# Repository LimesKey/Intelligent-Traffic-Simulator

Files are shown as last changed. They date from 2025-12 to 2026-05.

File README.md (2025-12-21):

# Intelligent-Traffic-Simulator

> [!NOTE]
> Work in progress - Everything has shown to be working individually but has not came together as a whole yet

Detect how hot wheels cars navigate streets and interact with stop lights and how this can be applied to the real world. Just a thing I made for class

It detects hot wheels cars via the three coils embedded in the PCB traces. The coils are hooked up to a 555 timer at around 200 KHz and when the hot wheels car is over the coil, the frequency changes which is detected by the ESP32 running a pulse counter script. Essentially a metal/object detector specifically calibrated for hot wheels cars.

Potentiometers are just for debugging / testing out various configurations. There is a multiplexer hooked up to the ESP32 so that one microcontroller can control multiple LEDs for multiple traffic lights.

I made some small mistakes, but I believe I updated the schematic to reflect the changes I made to make it work.

### Todo: 
* better ESD/current backflow protection 
* have esp32 fully inside PCB outline rather than sticking out
* remove extra testpoints / optvbvvcional components now that I know what works
* look into using a general oscillator rather than a 555 timer for better performance/cost
* somehow make the usb-c connector much easier to solder, it's killing me how difficult it is
* integrate `object-detection.ino` with `dutch_traffic_light_code.ino`

# Media
## JLCPCB Ordered, Hand Assembled
<p align="center">
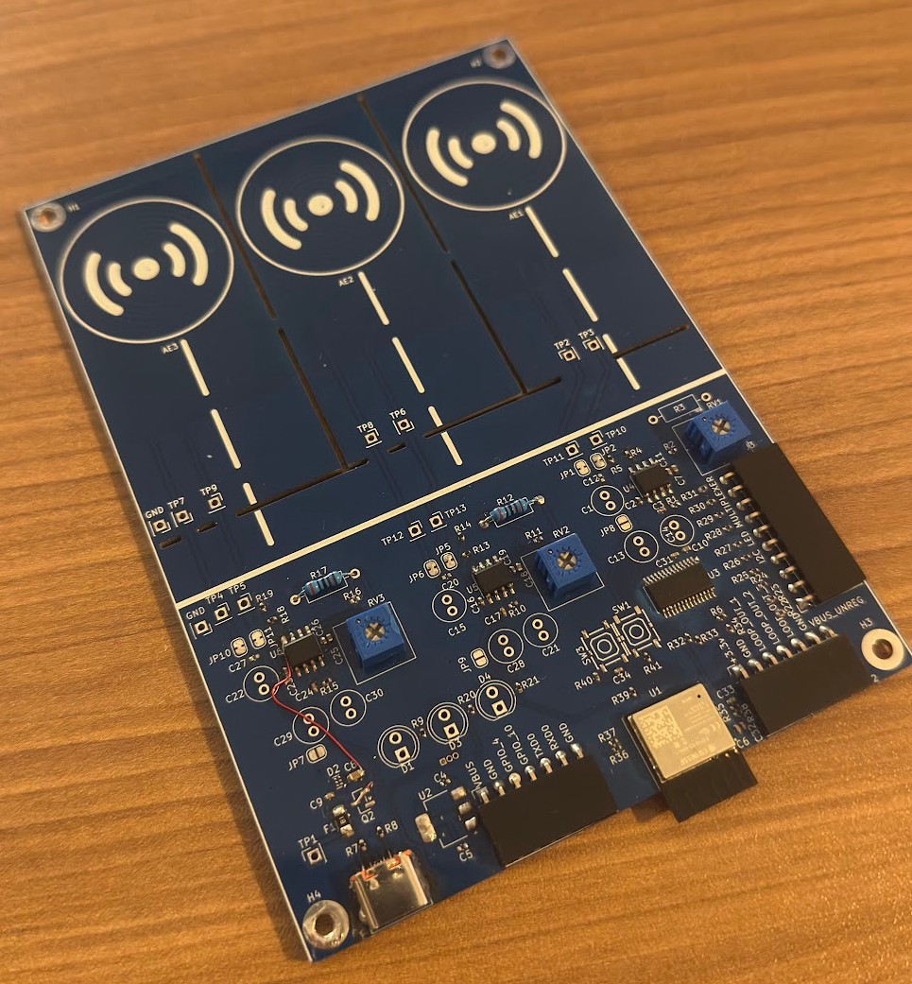
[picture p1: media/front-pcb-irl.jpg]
Assembled PCB front
  
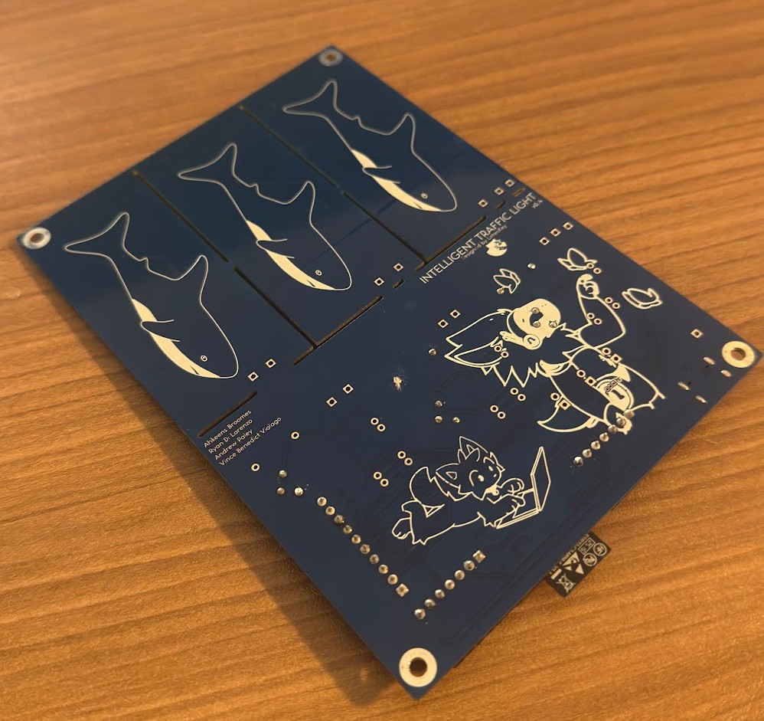
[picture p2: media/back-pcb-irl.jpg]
Assembled PCB back
  
</p>

## KiCad
### PCB 3D Viewer
<div style="display:flex; justify-content:center; gap:16px;">
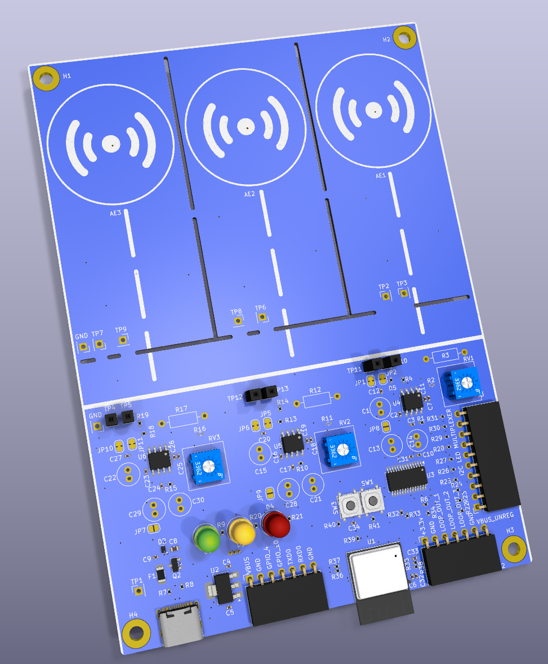
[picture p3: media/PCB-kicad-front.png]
KiCad PCB front
  
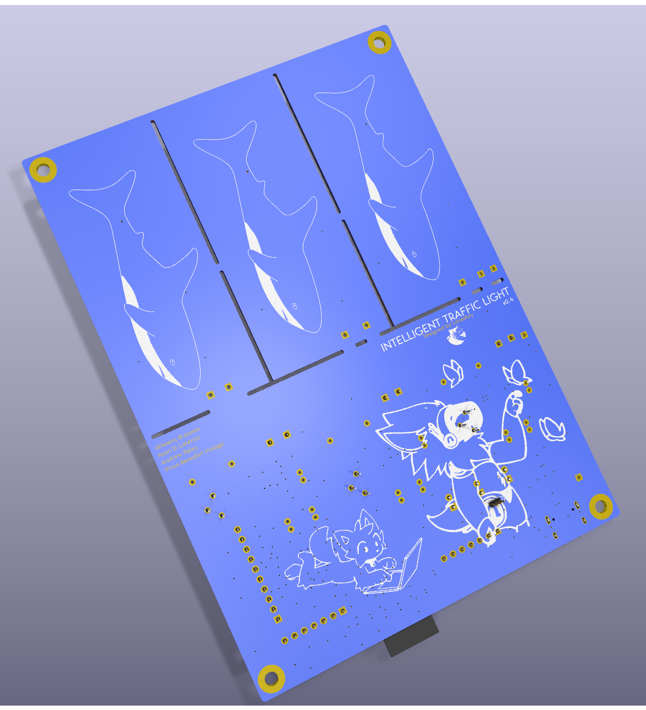
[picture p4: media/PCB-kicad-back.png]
KiCad PCB back
  
</div>

### Schematic

<h4 align="center">Main controller</h4>
KiCad Schematic of main control electronics like microcontroler / signal processing

<h4 align="center">555 Timer Circuitry</h4>
KiCad Schematic of metal detecting circuit

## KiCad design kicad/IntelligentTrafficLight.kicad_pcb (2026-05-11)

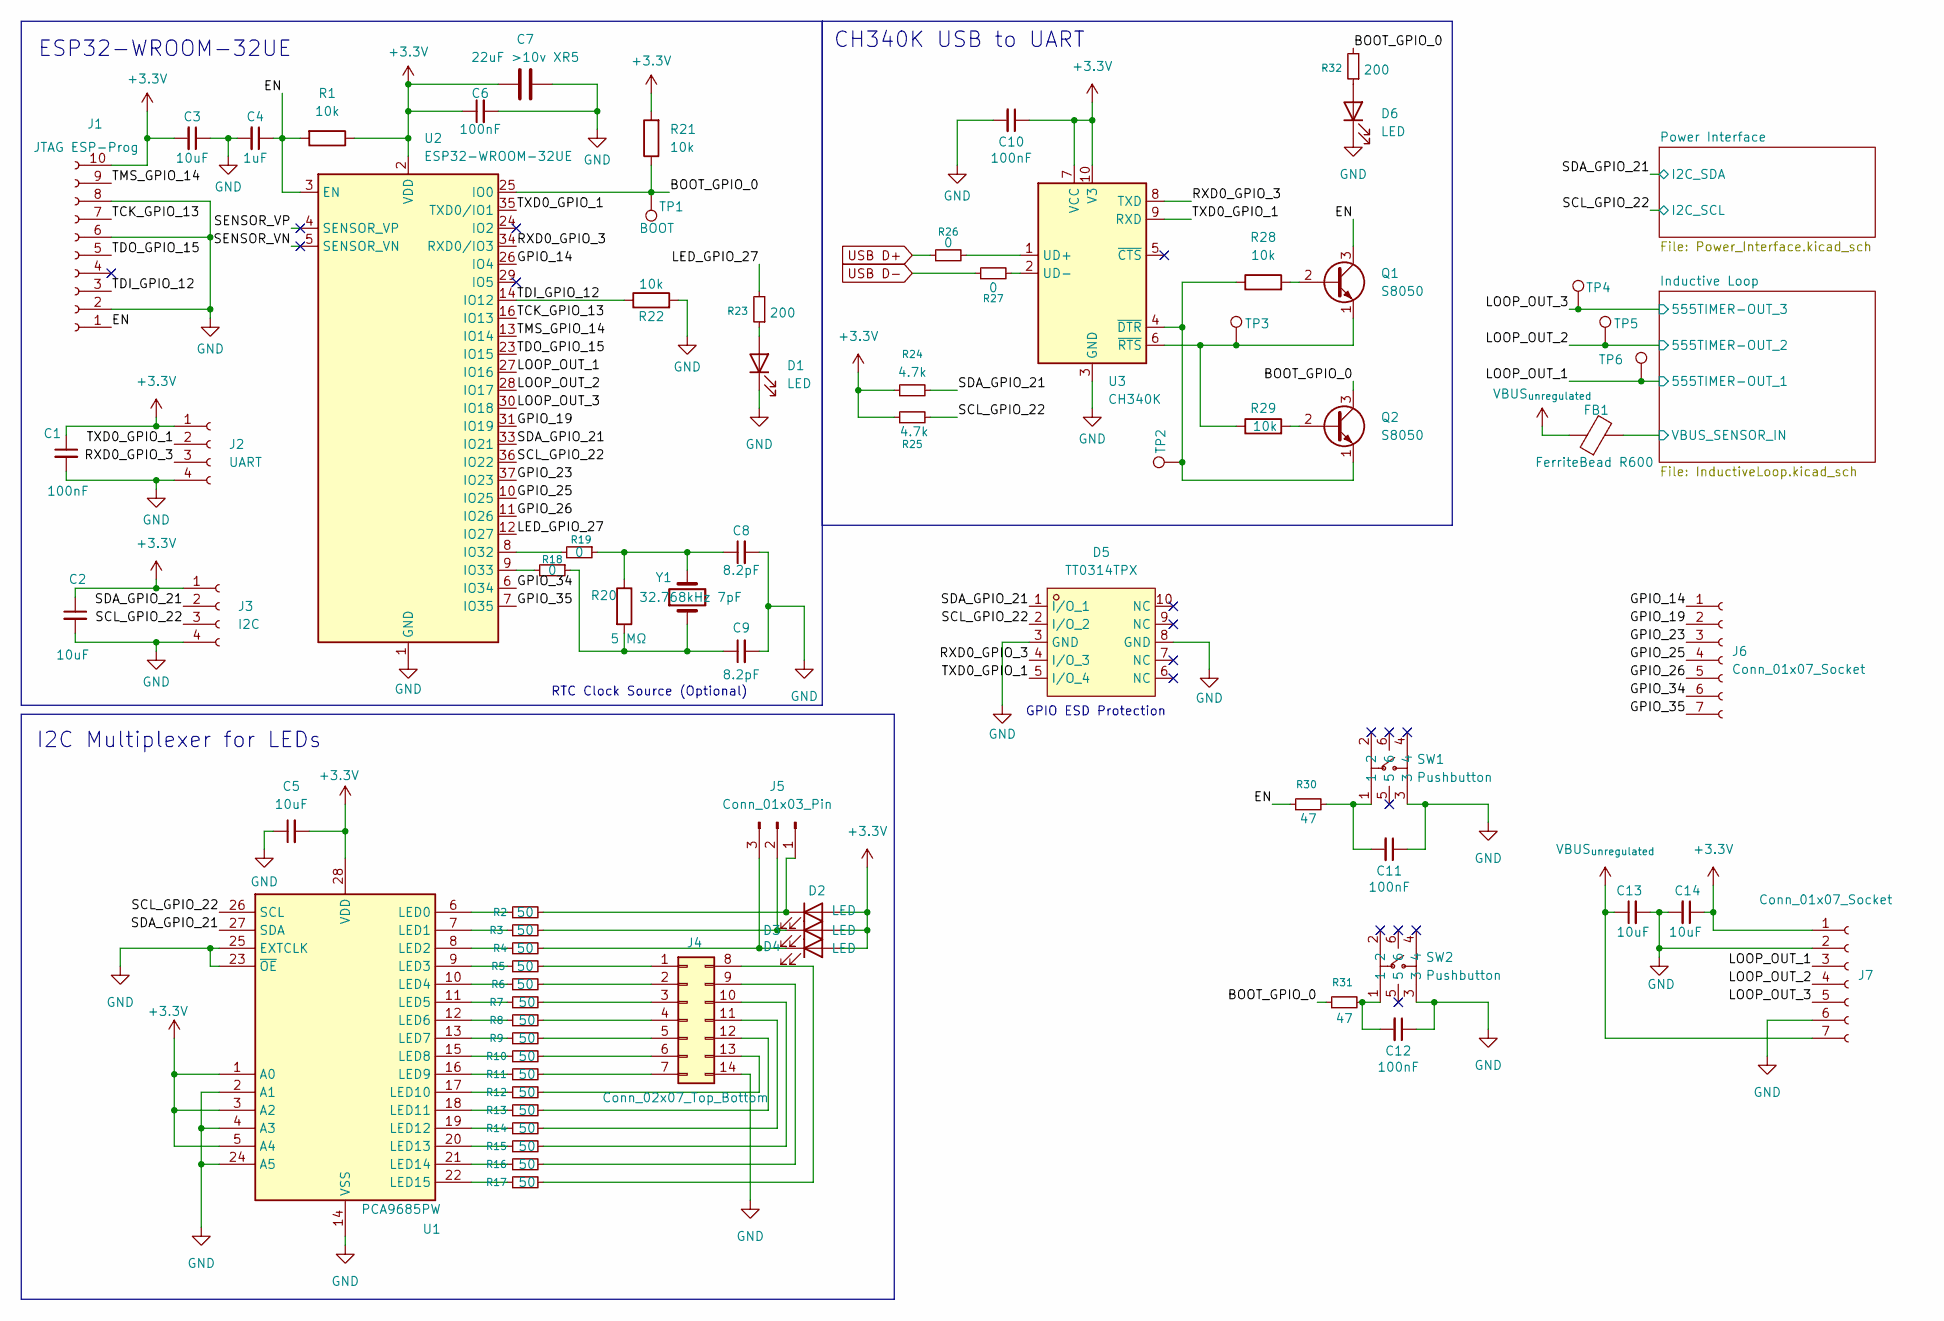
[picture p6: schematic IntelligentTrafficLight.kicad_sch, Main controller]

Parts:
C1, C6, C10, C11, C12: 100nF; C_0402_1005Metric
C2, C3, C5: 10uF; C_0402_1005Metric
C4: 1uF; C_0402_1005Metric
C7: 22uF >10v XR5; C_0805_2012Metric
C8, C9: 8.2pF; C_0402_1005Metric; LCSC Part C2857971
C13, C14: 10uF; C_0402_1005Metric; LCSC Part C33595851
D1, D2, D3, D4, D6: LED; LED_D5.0mm
D5: TT0314TPX; DFN2510-10_L2.5-W1.0-P0.50-BL; LCSC Part C5307962
FB1: FerriteBead R600; L_0603_1608Metric
J1: JTAG ESP-Prog; PinSocket_1x10_P2.54mm_Horizontal
J2: UART; PinSocket_1x04_P2.54mm_Horizontal
J3: I2C; PinSocket_1x04_P2.54mm_Horizontal
J4: Conn_02x07_Top_Bottom; PinSocket_2x07_P2.54mm_Horizontal
J5: Conn_01x03_Pin; PinHeader_1x03_P1.00mm_Vertical
J6, J7: Conn_01x07_Socket; PinSocket_1x07_P2.54mm_Horizontal
Q1, Q2: S8050; TO-92_Inline
R1, R21, R22, R28, R29: 10k; R_0402_1005Metric
R2, R3, R4, R5, R6, R7, R8, R9, R10, R11, R12, R13, R14, R15, R16, R17: 50; R_0402_1005Metric
R18, R19, R26, R27: 0; R_0603_1608Metric
R20: 5 MΩ; R_0402_1005Metric
R23, R32: 200; R_0402_1005Metric
R24, R25: 4.7k; R_0402_1005Metric
R30, R31: 47; R_0402_1005Metric
SW1, SW2: Pushbutton; SW-SMD_6P-L5.2-W5.2-P3.70-LS6.4; LCSC Part C2848968
TP1: BOOT; TestPoint_Bridge_Pitch2.54mm_Drill0.7mm
TP2: DTR; TestPoint_Bridge_Pitch2.54mm_Drill0.7mm
TP3: RTS; TestPoint_Bridge_Pitch2.54mm_Drill0.7mm
TP4: LOOP_OUT_3; TestPoint_Bridge_Pitch2.54mm_Drill0.7mm
TP5: LOOP_OUT_2; TestPoint_Bridge_Pitch2.54mm_Drill0.7mm
TP6: LOOP_OUT_1; TestPoint_Bridge_Pitch2.54mm_Drill0.7mm
U1: PCA9685PW; TSSOP-28_4.4x9.7mm_P0.65mm; LCSC Part C2678753
U2: ESP32-WROOM-32UE
U3: CH340K; SSOP-10-1EP_3.9x4.9mm_P1mm_EP2.1x3.3mm
Y1: 32.768kHz 7pF; Crystal_SMD_2012-2Pin_2.0x1.2mm_HandSoldering; LCSC Part C2905364

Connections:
+3.3V: C1.1, C2.1, C3.2, C5.2, C6.1, C7.1, C10.1, C14.1, D2.2 (A), D3.2 (A), D4.2 (A), J1.10, J2.1, J3.1, J7.1, R1.1, R21.2, R24.1, R25.1, U1.1 (A0), U1.3 (A2), U1.5 (A4), U1.28 (VDD), U2.2 (VDD), U3.7 (VCC), U3.10 (V3); also elsewhere on the board
/BOOT_GPIO_0: Q2.3 (C), R21.1, R31.1, R32.2, TP1.1 (1_1), U2.25 (IO0)
/EN: C4.1, J1.1, Q1.3 (C), R1.2, R30.1, U2.3 (EN)
/GPIO_14: J6.1, U2.26 (IO4)
/GPIO_19: J6.2, U2.31 (IO19)
/GPIO_23: J6.3, U2.37 (IO23)
/GPIO_25: J6.4, U2.10 (IO25)
/GPIO_26: J6.5, U2.11 (IO26)
/GPIO_34: J6.6, U2.6 (IO34)
/GPIO_35: J6.7, U2.7 (IO35)
/Inductive Loop/VBUS_SENSOR_IN: FB1.2; also elsewhere on the board
/LED_GPIO_27: R23.2, U2.12 (IO27)
/LOOP_OUT_1: J7.3, TP6.1 (1_1), U2.27 (IO16); also elsewhere on the board
/LOOP_OUT_2: J7.4, TP5.1 (1_1), U2.28 (IO17); also elsewhere on the board
/LOOP_OUT_3: J7.5, TP4.1 (1_1), U2.30 (IO18); also elsewhere on the board
/RXD0_GPIO_3: D5.4 (I/O_3), J2.3, U2.34 (RXD0/IO3), U3.8 (TXD)
/SCL_GPIO_22: D5.2 (I/O_2), J3.3, R25.2, U1.26 (SCL), U2.36 (IO22); also elsewhere on the board
/SDA_GPIO_21: D5.1 (I/O_1), J3.2, R24.2, U1.27 (SDA), U2.33 (IO21); also elsewhere on the board
/SENSOR_VN: U2.5 (SENSOR_VN)
/SENSOR_VP: U2.4 (SENSOR_VP)
/TCK_GPIO_13: J1.7, U2.16 (IO13)
/TDI_GPIO_12: J1.3, R22.1, U2.14 (IO12)
/TDO_GPIO_15: J1.5, U2.23 (IO15)
/TMS_GPIO_14: J1.9, U2.13 (IO14)
/TXD0_GPIO_1: D5.5 (I/O_4), J2.2, U2.35 (TXD0/IO1), U3.9 (RXD)
GND: C1.2, C2.2, C3.1, C4.2, C5.1, C6.2, C7.2, C8.2, C9.2, C10.2, C11.1, C12.1, C13.2, C14.2, D1.1 (K), D5.3 (GND), D5.8 (GND), D6.1 (K), J1.2, J1.6, J1.8, J2.4, J3.4, J4.14, J7.2, J7.6, R22.2, SW1.3, SW2.3, U1.2 (A1), U1.4 (A3), U1.14 (VSS), U1.23 (~OE), U1.24 (A5), U1.25 (EXTCLK), U2.1 (GND), U2.15 (GND), U2.38 (GND), U2.39 (GND), U3.3 (GND), U3.11 (GND); also elsewhere on the board
unnamed: C8.1, R19.1, R20.1, Y1.2
unnamed: C9.1, R18.1, R20.2, Y1.1
unnamed: C11.2, R30.2, SW1.1
unnamed: C12.2, R31.2, SW2.1
unnamed: D1.2 (A), R23.1
unnamed 35: D2.1 (K), J5.1, R2.2; also elsewhere on the board
unnamed: D3.1 (K), J5.2, R3.2
unnamed 37: D4.1 (K), J5.3, R4.2; also elsewhere on the board
unnamed: D6.2 (A), R32.1
unnamed 41: J4.1, R5.2; also elsewhere on the board
unnamed 42: J4.2, R6.2; also elsewhere on the board
unnamed: J4.3, R7.2
unnamed: J4.4, R8.2
unnamed: J4.5, R9.2
unnamed: J4.6, R10.2
unnamed: J4.7, R11.2
unnamed: J4.8, R17.2
unnamed: J4.9, R16.2
unnamed: J4.10, R15.2
unnamed: J4.11, R14.2
unnamed: J4.12, R13.2
unnamed: J4.13, R12.2
unnamed: Q1.2 (B), R28.2
unnamed: Q1.1 (E), R29.1, TP3.1 (1_1), U3.6 (~RTS)
unnamed: Q2.2 (B), R29.2
unnamed: Q2.1 (E), R28.1, TP2.1 (1_1), U3.4 (~DTR)
unnamed 75: R2.1, U1.6 (LED0); also elsewhere on the board
unnamed: R3.1, U1.7 (LED1)
unnamed 77: R4.1, U1.8 (LED2); also elsewhere on the board
unnamed 78: R5.1, U1.9 (LED3); also elsewhere on the board
unnamed 79: R6.1, U1.10 (LED4); also elsewhere on the board
unnamed: R7.1, U1.11 (LED5)
unnamed: R8.1, U1.12 (LED6)
unnamed: R9.1, U1.13 (LED7)
unnamed: R10.1, U1.15 (LED8)
unnamed: R11.1, U1.16 (LED9)
unnamed: R12.1, U1.17 (LED10)
unnamed: R13.1, U1.18 (LED11)
unnamed: R14.1, U1.19 (LED12)
unnamed: R15.1, U1.20 (LED13)
unnamed: R16.1, U1.21 (LED14)
unnamed: R17.1, U1.22 (LED15)
unnamed: R19.2, U2.8 (IO32)
unnamed: R18.2, U2.9 (IO33)
unnamed: R26.2, U3.1 (UD+)
unnamed: R27.2, U3.2 (UD-)
USB D+: R26.1; also elsewhere on the board
USB D-: R27.1; also elsewhere on the board
VBUS_{unregulated}: C13.1, FB1.1, J7.7; also elsewhere on the board

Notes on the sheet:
RTC Clock Source (Optional)
ESP32-WROOM-32UE
GPIO ESD Protection
I2C Multiplexer for LEDs
CH340K USB to UART

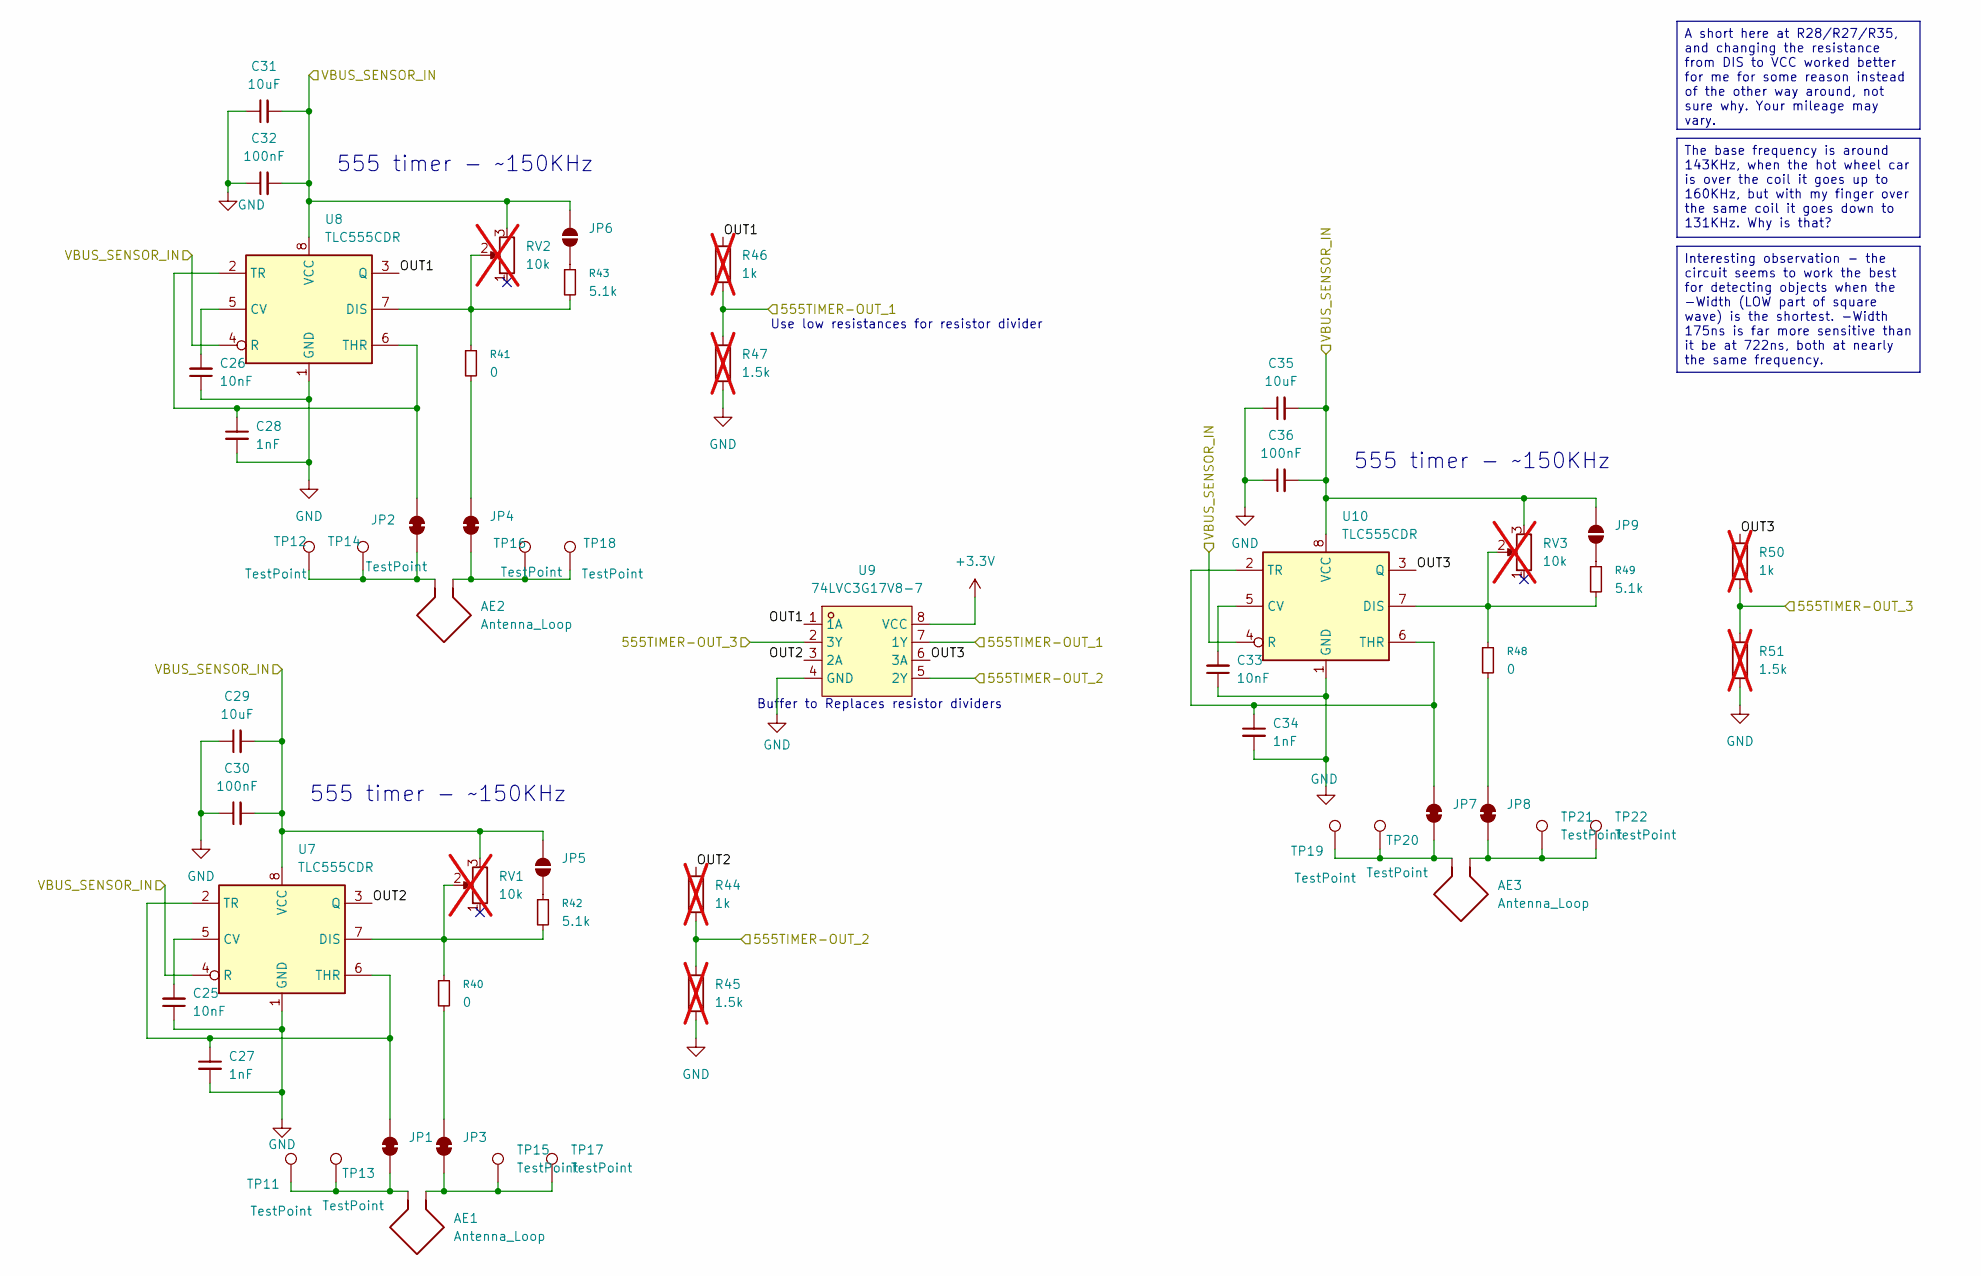
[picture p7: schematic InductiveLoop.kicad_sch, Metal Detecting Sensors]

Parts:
AE1, AE2, AE3: Antenna_Loop; HOTWHEEL_DETECTOR
C25, C26, C33: 10nF; C_0402_1005Metric
C27, C28, C34: 1nF; C_0402_1005Metric
C29, C31, C35: 10uF; C_0402_1005Metric
C30, C32, C36: 100nF; C_0402_1005Metric
JP1, JP2, JP3, JP4, JP7, JP8: SolderJumper_2_Bridged; SolderJumper-2_P1.3mm_Bridged_RoundedPad1.0x1.5mm
JP5, JP6, JP9: SolderJumper_2_Open; SolderJumper-2_P1.3mm_Open_RoundedPad1.0x1.5mm
R40, R41, R48: 0; R_0402_1005Metric
R42, R49: 5.1k; R_0402_1005Metric
R43: 5.1k; R_Axial_DIN0207_L6.3mm_D2.5mm_P10.16mm_Horizontal
R44, R46, R50: 1k; R_0402_1005Metric; not fitted
R45, R47, R51: 1.5k; R_0402_1005Metric; not fitted
RV1, RV2, RV3: 10k; Potentiometer_Bourns_3386P_Vertical; LCSC Part C118956; not fitted
TP11, TP12, TP13, TP14, TP15, TP16, TP17, TP18, TP19, TP20, TP21, TP22: TestPoint; PinSocket_1x01_P2.54mm_Vertical
U7, U8, U10: TLC555CDR; SOIC-8_3.9x4.9mm_P1.27mm; LCSC Part C6986
U9: 74LVC3G17V8-7; VSSOP-8_L2.1-W2.4-P0.50-LS3.2-BL; MPN 74LVC3G17V8-7; LCSC Part C19948350

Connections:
+3.3V: U9.8 (VCC); also elsewhere on the board
/Inductive Loop/OUT1: R46.1, U8.3 (Q), U9.1 (1A)
/Inductive Loop/OUT2: R44.1, U7.3 (Q), U9.3 (2A)
/Inductive Loop/OUT3: R50.1, U9.6 (3A), U10.3 (Q)
/Inductive Loop/VBUS_SENSOR_IN: C29.2, C30.2, C31.2, C32.2, C35.2, C36.2, JP5.2 (B), JP6.2 (B), JP9.2 (B), RV1.3, RV2.3, RV3.3, U7.4 (R), U7.8 (VCC), U8.4 (R), U8.8 (VCC), U10.4 (R), U10.8 (VCC); also elsewhere on the board
/LOOP_OUT_1: R46.2, R47.1, U9.7 (1Y); also elsewhere on the board
/LOOP_OUT_2: R44.2, R45.1, U9.5 (2Y); also elsewhere on the board
/LOOP_OUT_3: R50.2, R51.1, U9.2 (3Y); also elsewhere on the board
GND: C25.1, C26.1, C27.2, C28.2, C29.1, C30.1, C31.1, C32.1, C33.1, C34.2, C35.1, C36.1, R45.2, R47.2, R51.2, U7.1 (GND), U8.1 (GND), U9.4 (GND), U10.1 (GND); also elsewhere on the board
unnamed: AE1.2, JP1.1 (A), TP11.1 (1_1), TP13.1 (1_1)
unnamed: C27.1, JP1.2 (B), U7.2 (TR), U7.6 (THR)
unnamed: AE2.2, JP2.1 (A), TP12.1 (1_1), TP14.1 (1_1)
unnamed: C28.1, JP2.2 (B), U8.2 (TR), U8.6 (THR)
unnamed: AE1.1, JP3.1 (A), TP15.1 (1_1), TP17.1 (1_1)
unnamed: JP3.2 (B), R40.2
unnamed: AE2.1, JP4.1 (A), TP16.1 (1_1), TP18.1 (1_1)
unnamed: JP4.2 (B), R41.2
unnamed: JP5.1 (A), R42.1
unnamed: JP6.1 (A), R43.1
unnamed: AE3.2, JP7.1 (A), TP19.1 (1_1), TP20.1 (1_1)
unnamed: C34.1, JP7.2 (B), U10.2 (TR), U10.6 (THR)
unnamed: AE3.1, JP8.1 (A), TP21.1 (1_1), TP22.1 (1_1)
unnamed: JP8.2 (B), R48.2
unnamed: JP9.1 (A), R49.1
unnamed: C25.2, U7.5 (CV)
unnamed: R40.1, R42.2, RV1.2, U7.7 (DIS)
unnamed: C26.2, U8.5 (CV)
unnamed: R41.1, R43.2, RV2.2, U8.7 (DIS)
unnamed: C33.2, U10.5 (CV)
unnamed: R48.1, R49.2, RV3.2, U10.7 (DIS)

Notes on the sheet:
Buffer to Replaces resistor dividers
555 timer - ~150KHz
Use low resistances for resistor divider
Interesting observation - the circuit seems to work the best for detecting objects when the -Width (LOW part of square wave) is the shortest. -Width 175ns is far more sensitive than it be at 722ns, both at nearly the same frequency.
The base frequency is around 143KHz, when the hot wheel car is over the coil it goes up to 160KHz, but with my finger over the same coil it goes down to 131KHz. Why is that?
A short here at R28/R27/R35, and changing the resistance from DIS to VCC worked better for me for some reason instead of the other way around, not sure why. Your mileage may vary.

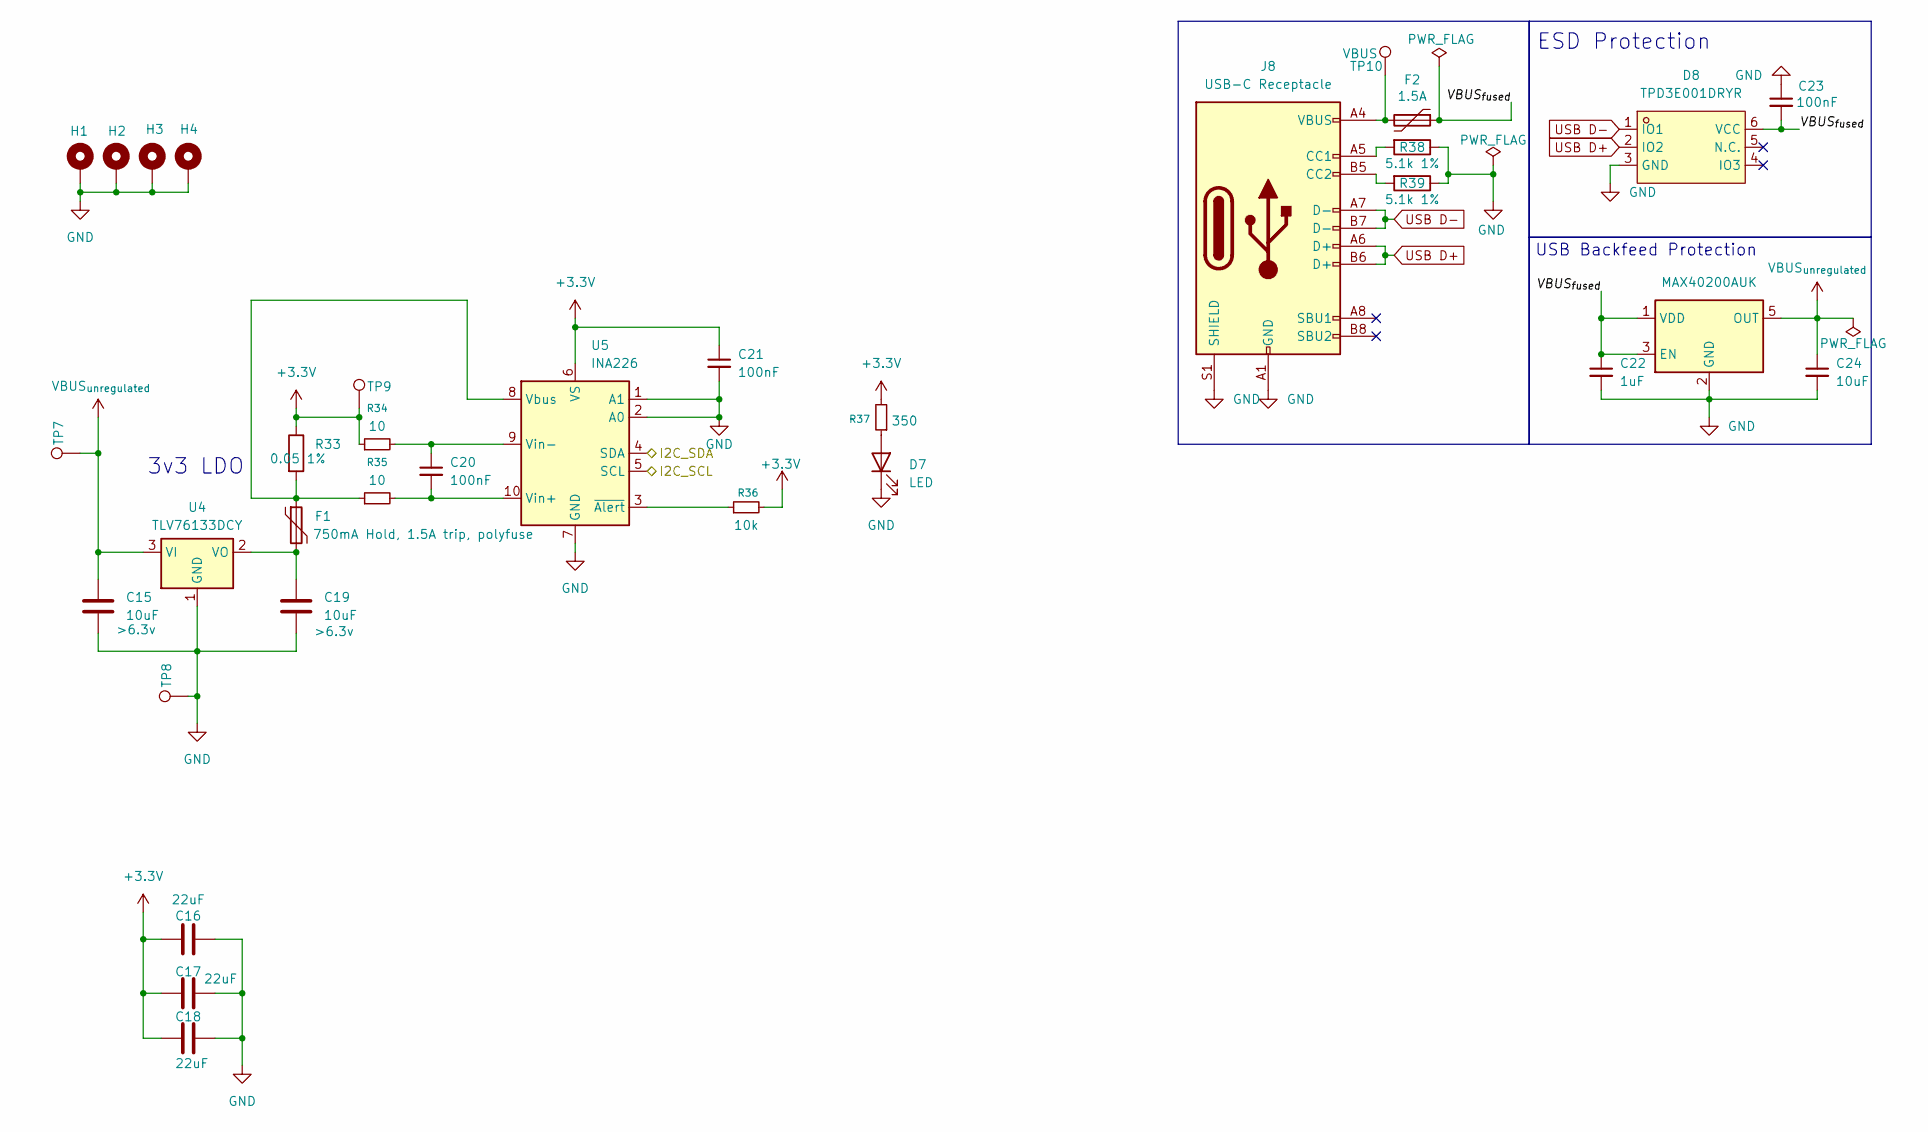
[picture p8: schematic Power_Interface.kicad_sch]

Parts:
C15, C19: 10uF; C_0402_1005Metric; Voltage Rating >6.3v
C16, C17, C18: 22uF; C_0805_2012Metric; LCSC Part C7472967
C20, C21: 100nF; C_0402_1005Metric
C22: 1uF; C_0402_1005Metric
C23: 100nF; C_0402_1005Metric; LCSC Part C392963
C24: 10uF; C_0402_1005Metric
D7: LED; LED_D5.0mm
D8: TPD3E001DRYR; Texas_USON-6_1x1.45mm_P0.5mm_SMD; LCSC Part C5122047
F1: 750mA Hold, 1.5A trip, polyfuse; Fuse_1812_4532Metric; LCSC Part C49318440
F2: 1.5A; Fuse_1206_3216Metric_Pad1.42x1.75mm_HandSolder; LCSC Part C883133
H1, H2, H3, H4: MountingHole_Pad; MountingHole_3.2mm_M3_Pad
J8: USB-C Receptacle; USB_C_Receptacle_G-Switch_GT-USB-7010ASV; LCSC Part C963413
R33: 0.05 1%; R_2512_6332Metric; LCSC Part C49164908
R34, R35: 10; R_0402_1005Metric
R36: 10k; R_0402_1005Metric
R37: 350; R_0402_1005Metric
R38, R39: 5.1k 1%; R_0402_1005Metric; LCSC Part C2906874
TP7: VBUSunreg; TestPoint_Bridge_Pitch2.54mm_Drill0.7mm
TP8: LOOP_OUT_2; TestPoint_Bridge_Pitch2.54mm_Drill0.7mm
TP9: 3V3; TestPoint_Bridge_Pitch2.54mm_Drill0.7mm
TP10: VBUS; PinSocket_1x01_P2.54mm_Vertical
U4: TLV76133DCY; SOT-223-3_TabPin2; LCSC Part C7527500
U5: INA226; TSSOP-10_3x3mm_P0.5mm
U6: MAX40200AUK; SOT-23-5

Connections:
+3.3V: C16.1, C17.1, C18.1, C21.1, R33.1, R34.1, R36.2, R37.2, TP9.1 (1_1), U5.6 (VS); also elsewhere on the board
/Power Interface/VBUS_{fused}: C22.1, C23.2, D8.6 (VCC), F2.1, U6.1 (VDD), U6.3 (EN)
/SCL_GPIO_22: U5.5 (SCL); also elsewhere on the board
/SDA_GPIO_21: U5.4 (SDA); also elsewhere on the board
GND: C15.2, C16.2, C17.2, C18.2, C19.2, C21.2, C22.2, C23.1, C24.2, D7.1 (K), D8.3 (GND), H1.1 (1_1), H2.1 (1_1), H3.1 (1_1), H4.1 (1_1), J8.A1 (GND), J8.A12 (GND), J8.B1 (GND), J8.B12 (GND), J8.S1 (SHIELD), R38.1, R39.1, TP8.1 (1_1), U4.1 (GND), U5.1 (A1), U5.2 (A0), U5.7 (GND), U6.2 (GND); also elsewhere on the board
unnamed: D7.2 (A), R37.1
unnamed: F2.2, J8.A4 (VBUS), J8.A9 (VBUS), J8.B4 (VBUS), J8.B9 (VBUS), TP10.1 (1_1)
unnamed: J8.A5 (CC1), R38.2
unnamed: J8.B5 (CC2), R39.2
unnamed: C19.1, F1.2, U4.2 (VO)
unnamed: F1.1, R33.2, R35.1, U5.8 (Vbus)
unnamed: C20.2, R35.2, U5.10 (Vin+)
unnamed: C20.1, R34.2, U5.9 (Vin-)
unnamed: R36.1, U5.3 (~Alert)
USB D+: D8.2 (IO2), J8.A6 (D+), J8.B6 (D+); also elsewhere on the board
USB D-: D8.1 (IO1), J8.A7 (D-), J8.B7 (D-); also elsewhere on the board
VBUS_{unregulated}: C15.1, C24.1, TP7.1 (1_1), U4.3 (VI), U6.5 (OUT); also elsewhere on the board

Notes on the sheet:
3v3 LDO
USB Backfeed Protection
ESD Protection

Board: 4 copper layers, 168 parts (71 on the bottom side), 107 nets, no tracks yet.

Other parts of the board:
R2#2, R4#2, R5#2, R6#2: 50; R_0402_1005Metric
kibuzzard-691D01BA: G***; kibuzzard-691D01BA
kibuzzard-691D028C: G***; kibuzzard-691D028C

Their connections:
unnamed 35: R2#2.2; also elsewhere on the board
unnamed 37: R4#2.2; also elsewhere on the board
unnamed 41: R5#2.2; also elsewhere on the board
unnamed 42: R6#2.2; also elsewhere on the board
unnamed 75: R2#2.1; also elsewhere on the board
unnamed 77: R4#2.1; also elsewhere on the board
unnamed 78: R5#2.1; also elsewhere on the board
unnamed 79: R6#2.1; also elsewhere on the board

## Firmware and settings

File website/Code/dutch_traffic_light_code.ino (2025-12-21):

// Made by cyborgsheep9574

// NR = 10,NY = 9,NG = 8;
// WR = 13,WY = 12,WG = 11;
// SR = 4,SY = 3,SG = 2;
// ER = 7,EY = 6,EG = 5;
// Variables will change:
int color1 = 3, color2 = 3, color3 = 3, color4 = 3;  // used to choose signal state

// Generally, you should use "unsigned long" for variables that hold time
// The value will quickly become too large for an int to store
unsigned long previousMillis = 0,previousMillis1 = 0;  // will store last time LED was updated

// constants won't change:
long interval1 = 0,interval2 = 0;  // interval at which to blink (milliseconds)
//const long RDint1 = 160, RDint2 = 640, Chngint = 3000;
int SW1,SW2,SW3,SW4;

void setup() {
  // set the digital pin as output:
  pinMode(13, OUTPUT);
  pinMode(10,OUTPUT);
  pinMode(9,OUTPUT);
  pinMode(8,OUTPUT);
  pinMode(7,OUTPUT);
  pinMode(6,OUTPUT);
  pinMode(5,OUTPUT);
  pinMode(4,OUTPUT);
  pinMode(3,OUTPUT);
  pinMode(2,OUTPUT);
  pinMode(12,OUTPUT);
  pinMode(11,OUTPUT);
  Serial.begin(9600);
  color1 = 3;
  color2 = 3;
  color3 = 3;
  color4 = 3;
  digitalWrite(10,HIGH);
  digitalWrite(13,HIGH);
  digitalWrite(4,HIGH);
  digitalWrite(7,HIGH);
}

void loop() {
  // here is where you'd put code that needs to be running all the time.
  Serial.print(interval1);
  Serial.println(interval2);
  //read inputs
  SW1 = digitalRead(A0); //northbound sensor 
  SW2 = digitalRead(A1); //eastbound sensor
  SW3 = digitalRead(A2); //southbound sensor
  SW4 = digitalRead(A3); //westbound sensor
  
  // check to see if it's time to blink the LED; that is, if the difference
  // between the current time and last time you blinked the LED is bigger than
  // the interval at which you want to blink the LED.
  unsigned long currentMillis = millis();
  
  if (currentMillis - previousMillis >= interval1) {
    // save the last time you blinked the LED
    previousMillis = currentMillis;

    // if the LED is off turn it on and vice-versa:
 if (SW4 == 1 || color1 != 3){ // westbound logic
    if (color1 == 3 && color2 == 3 && color4 == 3) {    // conflicting with northbound and southbound
      color1 = 1; // green
      interval1 = 5000;
      }else if (color1 == 1){
      color1 = 2; // yellow
      interval1 = 3790;
    }else{
      color1 = 3; //red
      interval1 = 640;
      }
       if(color1 == 1){
   digitalWrite(13,LOW);  //westbound green on
   digitalWrite(12,LOW);
   digitalWrite(11,HIGH);
    }else if(color1 == 2){
     digitalWrite(13,LOW);  //westbound yellow on
     digitalWrite(12,HIGH);
     digitalWrite(11,LOW);
      }else{
        digitalWrite(13,HIGH); //westbound red on
        digitalWrite(12,LOW);
        digitalWrite(11,LOW);
        }
 }
 if (SW1 == 1 || color2 != 3){ // northbound logic
    if (color2 == 3 && color1 == 3 && color3 == 3) { // conflicting with westbound and eastbound
      color2 = 1; // green
      interval1 = 5000;
    }else if (color2 == 1){
      color2 = 2; // yellow
      interval1 = 3790;
    }else{
      color2 = 3; //red
      interval1 = 640;
      }
  
 
    // set the signal with the color variable:
   
        if(color2 == 1){
   digitalWrite(10,LOW);  //northbound green on
   digitalWrite(9,LOW);
   digitalWrite(8,HIGH);
    }else if(color2 == 2){
     digitalWrite(10,LOW);  //northbound yellow on
     digitalWrite(9,HIGH);
     digitalWrite(8,LOW);
      }else{
        digitalWrite(10,HIGH); //northbound red on
        digitalWrite(9,LOW);
        digitalWrite(8,LOW);
        }
      
 }
  }  
  if (currentMillis - previousMillis1 >= interval2) {
    // save the last time you blinked the LED
    previousMillis1 = currentMillis; 
  
  if (SW2 == 1 || color3 != 3){ // eastbound logic 
    if (color3 == 3 && color2 == 3 && color4 == 3) {    // conflicting with northbound and southbound
      color3 = 1; // green
      interval2 = 5000;
    }else if (color3 == 1){
      color3 = 2; // yellow
      interval2 = 3790;
    }else{
      color3 = 3; //red
      interval2 = 640;
      }
      if(color3 == 1){
   digitalWrite(7,LOW);  //eastbound green on
   digitalWrite(6,LOW);
   digitalWrite(5,HIGH);
    }else if(color3 == 2){
     digitalWrite(7,LOW);  //eastbound yellow on
     digitalWrite(6,HIGH);
     digitalWrite(5,LOW);
      }else{
        digitalWrite(7,HIGH); //eastbound red on
        digitalWrite(6,LOW);
        digitalWrite(5,LOW);
        }
  }
    if (SW3 == 1 || color4 != 3){ // southbound logic 
    if (color4 == 3 && color1 == 3 && color3 == 3) {
      color4 = 1; // green
      interval2 = 5000;
    }else if (color4 == 1){
      color4 = 2; // yellow
      interval2 = 3790;
    }else{
      color4 = 3; //red
      interval2 = 640;
      }
      if(color4 == 1){
   digitalWrite(4,LOW);  //southbound green on
   digitalWrite(3,LOW);
   digitalWrite(2,HIGH);
    }else if(color4 == 2){
     digitalWrite(4,LOW);  //southbound yellow on
     digitalWrite(3,HIGH);
     digitalWrite(2,LOW);
      }else{
        digitalWrite(4,HIGH); //southbound red on
        digitalWrite(3,LOW);
        digitalWrite(2,LOW);
        }
  }
  }
}

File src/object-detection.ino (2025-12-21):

#include "driver/pcnt.h"

#define SIGNAL_PIN 4
#define PCNT_UNIT PCNT_UNIT_0
#define PCNT_CHANNEL PCNT_CHANNEL_0

#define CALIBRATION_MS 2000
#define DETECTION_THRESHOLD 0.015f  // 1%
#define SAMPLE_INTERVAL_MS 2       // high-resolution sampling
#define EMA_ALPHA 0.2f             // smoothing factor
#define PRINT_INTERVAL_MS 500      // update print every 500ms

// --- Calibration and EMA ---
float calibratedHighFreq = 0;
float calibratedLowFreq  = 0;

float freqHighEMA = 0;
float freqLowEMA  = 0;

// --- PCNT setup ---
void setupPCNT() {
    pcnt_config_t pcnt_cfg;
    pcnt_cfg.pulse_gpio_num = SIGNAL_PIN;
    pcnt_cfg.ctrl_gpio_num  = PCNT_PIN_NOT_USED;
    pcnt_cfg.channel        = PCNT_CHANNEL;
    pcnt_cfg.unit           = PCNT_UNIT;

    pcnt_cfg.pos_mode  = PCNT_COUNT_INC;   
    pcnt_cfg.neg_mode  = PCNT_COUNT_DIS;   
    pcnt_cfg.lctrl_mode = PCNT_MODE_KEEP;
    pcnt_cfg.hctrl_mode = PCNT_MODE_KEEP;

    pcnt_cfg.counter_h_lim = INT16_MAX;
    pcnt_cfg.counter_l_lim = INT16_MIN;

    pcnt_unit_config(&pcnt_cfg);
    pcnt_counter_pause(PCNT_UNIT);
    pcnt_counter_clear(PCNT_UNIT);
    pcnt_counter_resume(PCNT_UNIT);
}

// --- Calibration ---
void calibrateFrequency() {
    Serial.println("Calibrating HIGH/LOW frequencies...");
    unsigned long start = millis();
    int64_t sumHigh = 0, sumLow = 0;
    int cntHigh = 0, cntLow = 0;
    bool isHigh = false;

    while (millis() - start < CALIBRATION_MS) {
        delay(50);
        int16_t count;
        pcnt_get_counter_value(PCNT_UNIT, &count);
        pcnt_counter_clear(PCNT_UNIT);

        float freq = count * (1000.0f / 50.0f);

        if (isHigh) { sumHigh += freq; cntHigh++; }
        else        { sumLow  += freq; cntLow++; }

        isHigh = !isHigh;
    }

    calibratedHighFreq = cntHigh ? sumHigh / cntHigh : 0;
    calibratedLowFreq  = cntLow  ? sumLow  / cntLow  : 0;

    freqHighEMA = calibratedHighFreq;
    freqLowEMA  = calibratedLowFreq;

    Serial.printf("Calibration complete. HIGH=%.2f Hz, LOW=%.2f Hz\n", calibratedHighFreq, calibratedLowFreq);
}

// --- Setup ---
void setup() {
    Serial.begin(115200);
    pinMode(SIGNAL_PIN, INPUT);

    setupPCNT();
    calibrateFrequency();
}

// --- Loop ---
void loop() {
    static unsigned long lastSample = 0;
    static unsigned long lastPrint = 0;
    static bool isHigh = false;
    static bool metalDetectedHigh = false;
    static bool metalDetectedLow  = false;

    unsigned long now = millis();

    // High-resolution sampling
    if (now - lastSample >= SAMPLE_INTERVAL_MS) {
        lastSample = now;

        int16_t count;
        pcnt_get_counter_value(PCNT_UNIT, &count);
        pcnt_counter_clear(PCNT_UNIT);

        float freq = count * (1000.0f / SAMPLE_INTERVAL_MS);

        // --- Update EMA per phase ---
        if (isHigh) {
            freqHighEMA = EMA_ALPHA * freq + (1 - EMA_ALPHA) * freqHighEMA;
            metalDetectedHigh = (freqHighEMA > calibratedHighFreq * (1.0f + DETECTION_THRESHOLD));
        } else {
            freqLowEMA = EMA_ALPHA * freq + (1 - EMA_ALPHA) * freqLowEMA;
            metalDetectedLow = (freqLowEMA > calibratedLowFreq * (1.0f + DETECTION_THRESHOLD));
        }

        isHigh = !isHigh;
    }

    // Print update every 500ms
    if (now - lastPrint >= PRINT_INTERVAL_MS) {
        lastPrint = now;
        Serial.printf("HIGH EMA: %.2f Hz%s | LOW EMA: %.2f Hz%s\n",
                      freqHighEMA, metalDetectedHigh ? " [Metal!]" : "",
                      freqLowEMA,  metalDetectedLow  ? " [Metal!]" : "");
    }
}

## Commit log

2025-12-21 add code & website & pcb files
    [InductiveLoop.kicad_sch, IntelligentTrafficLight.kicad_pcb, IntelligentTrafficLight.kicad_sch]
2025-12-21 touchup filenames & directories, remove some files
    [InductiveLoop.kicad_sch, IntelligentTrafficLight.kicad_pcb, IntelligentTrafficLight.kicad_sch]
2025-12-22 add comments to kicad schematic
    [InductiveLoop.kicad_sch, IntelligentTrafficLight.kicad_pcb, IntelligentTrafficLight.kicad_sch]
2026-03-30 small pcb change
    [InductiveLoop.kicad_sch, IntelligentTrafficLight.kicad_sch]
2026-05-09 more updates
    [InductiveLoop.kicad_sch, IntelligentTrafficLight.kicad_sch, Power_Interface.kicad_sch]
